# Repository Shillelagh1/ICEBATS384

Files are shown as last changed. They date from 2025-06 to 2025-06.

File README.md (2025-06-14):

**ICE Boards are All The Same.**

> [!CAUTION]
> This project is a heavy work in progress in it's early stages.
> It would be greatly appreciated if you could review and provide feedback on my schematic,
> but it's heavily advised you don't attempt to build this board yet.

> [!IMPORTANT]
> Because of the intended small form factor of this board it may be difficult to manufacture for some.



# Summary:
This board is designed as a small universal FPGA daughterboard that can be added to any project without having to construct a unique layout for each project. It features a 40 pin mezzanine connector to attach to the parent board which offers access to all of the FPGA IO, Clock Hardware Controls, FPGA Configuration controls, and flash programming.

# Hardware:
+ Lattice ICE40LP384-SG32 FPGA.
+ Winbond W25X40C 4MBit Flash.
+ 16MHz Application configurable FPGA Clock.
+ Configuration done and Power OK status LEDs.
+ 2 User program controlled status LEDs.
+ 2mm Clearance daughterboard mezzanine connector.

# Footprint:
+ 30x15mm Overall Size
+ 25x10mm 2xM2 Mounting screw pattern (Diagonal)

# TODO:
- [X] Rough board layout.
- [ ] Peripheral boards (IO Breakout, Programming ribbon board, Automated test board).
- [ ] Final schematic review.
- [ ] First revision prototype.
- [ ] Prototype rework (Or it works first try?)
- [ ] All features test.
- [ ] Project integration.

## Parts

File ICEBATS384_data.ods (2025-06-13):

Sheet: PartsData
Part | Part Desc. | Purpose Desc. | Data Links
ICE40LP384-SG32 | FPGA
W25X40CLUXIG-TR | 4Mbit SPI Config Flash
MCP131T-315E/LB | Reset Controller/ Supervisor | Reset, Power OK
YF4016M00033T1521024: | 16MHz CMOS Oscillator | FPGA Clock
NCP114AMX120TCG | 1.2V LDO | Core Voltage
MCM3400A-TP | 2N-CH MOSFET Array | Status LED Driver
513389873 | 10 Position Mezzanine | Programming | Board-to-Board Connectors Part 513389873 | Molex (https://www.molex.com/en-us/products/part-detail/513389873)
559099872 |  | Mates with ABOVE | Board-to-Board Connectors Part 559099872 | Molex (https://www.molex.com/en-us/products/part-detail/559099872) | NOT PRESENT
5017450401 |  | Board Mating | Board-to-Board Connectors Part 5017450401 | Molex (https://www.molex.com/en-us/products/part-detail/5017450401)
513380474 | 40 Position Mezzanine | Mates with ABOVE | Board-to-Board Connectors Part 513380474 | Molex (https://www.molex.com/en-us/products/part-detail/513380474) | NOT PRESENT

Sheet: J1
Pin No. | Desc. | Pin No. | Desc.
1 | GND | 6 | Flash/FPGA Slave Select
2 | 3V3 | 7 | Config Reset
3 | Flash SDO / FPGA SDI | 8 | Flash Hold
4 | Flash SDI / FPGA SDO | 9 | N.C.
5 | Serial Clock | 10 | GND
In Circuit Flash Program Connection
V2 (Iter. From ICEDEMON board)

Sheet: J2
Part No. | Desc. | Part No. | Desc.
1 | GND | 21 | GND
2 | 3V3 | 22
3 | IO 18 | 23
4 | IO 19 | 24
5 | IO 20 | 25
6 | IO 22 | 26
7 | IO 23 | 27
8 | IO 26 | 28
9 | IO 27 | 29 | IO 15 / SCK
10 |  | 30 | IO 14 / SS
11 | 1V2 | 31 | IO 13 / FPGA SDI / Flash SDO
12 | Flash Hold | 32 | IO 12 / FPGA SDO / Flash SDI
13 | Config Done | 33 | IO 8
14 | Config Reset | 34 | IO 7
15 | Clock Enable | 35 | IO 6
16 | IO 29 | 36 | IO 5
17 | IO 30 | 37 | IO 2
18 | IO 31 | 38 | IO 1
19 | IO 32 | 39 | 3V3
20 | GND | 40 | GND

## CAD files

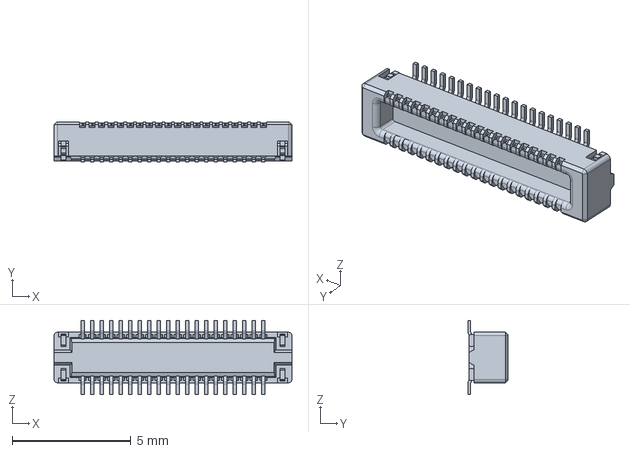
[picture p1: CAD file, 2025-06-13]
parts/daughterConnector/5017450401.stp
10.0 x 1.70 x 3.13 mm

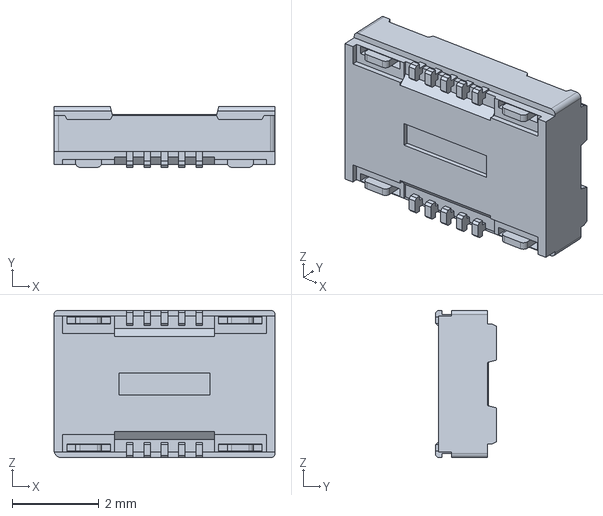
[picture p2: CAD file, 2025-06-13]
parts/prog_con/0513389873.stp
5.10 x 1.40 x 3.40 mm

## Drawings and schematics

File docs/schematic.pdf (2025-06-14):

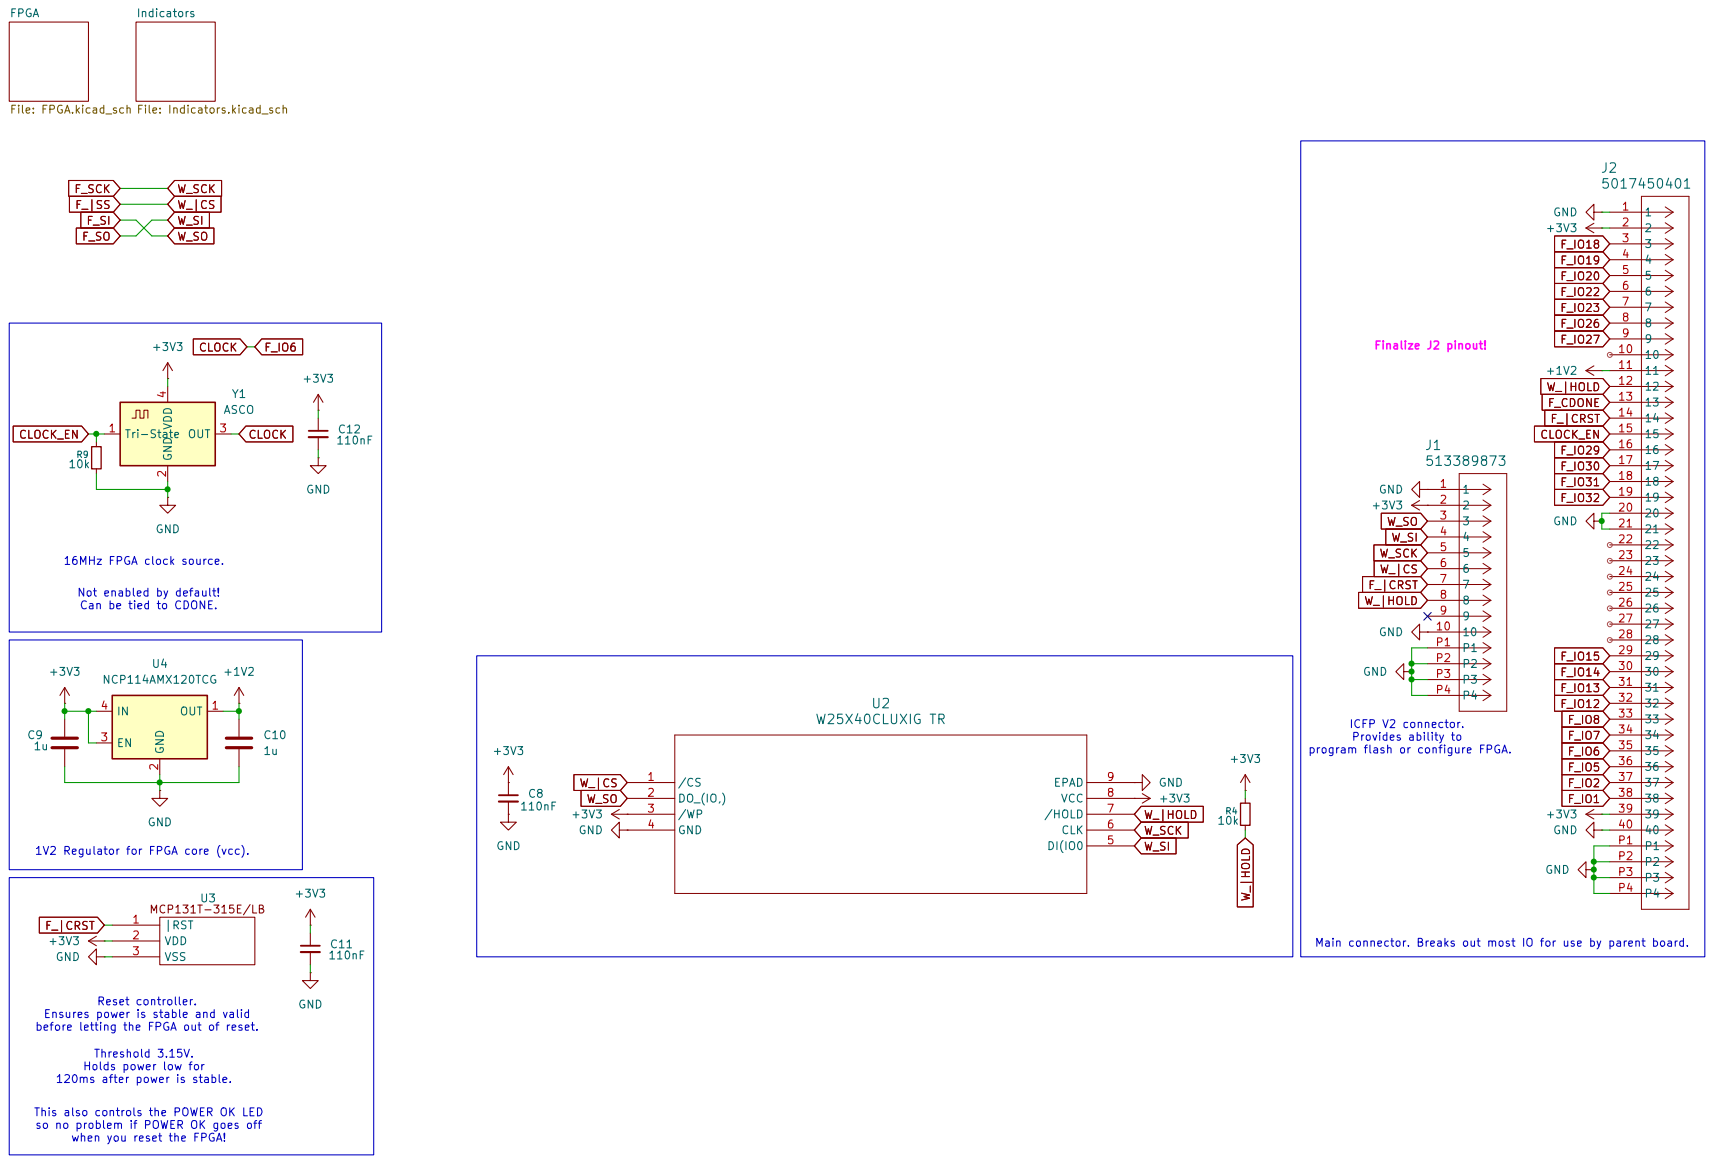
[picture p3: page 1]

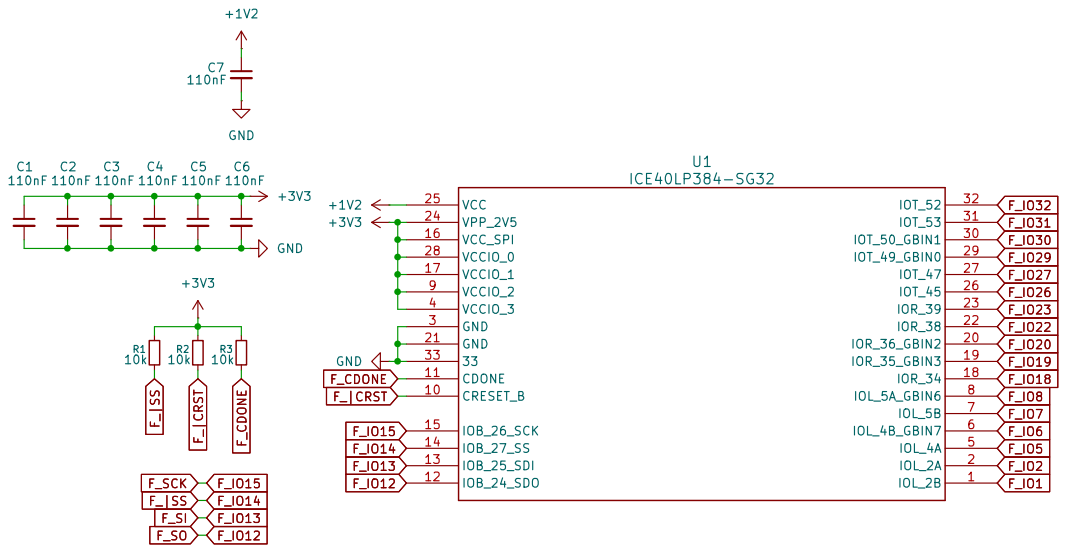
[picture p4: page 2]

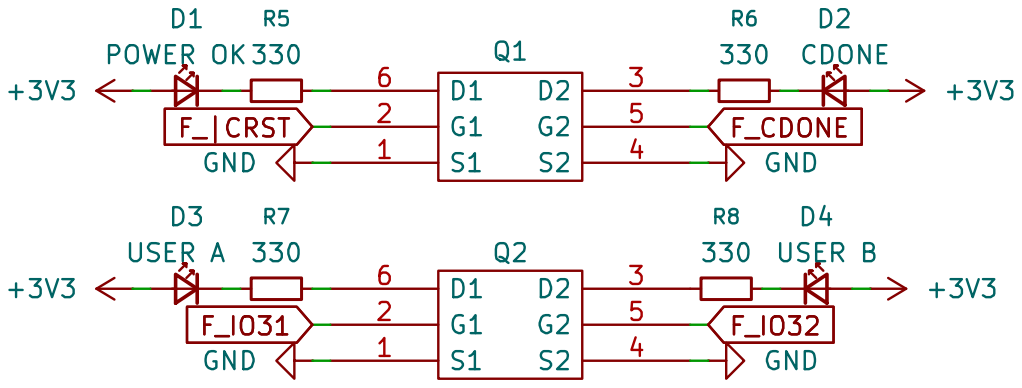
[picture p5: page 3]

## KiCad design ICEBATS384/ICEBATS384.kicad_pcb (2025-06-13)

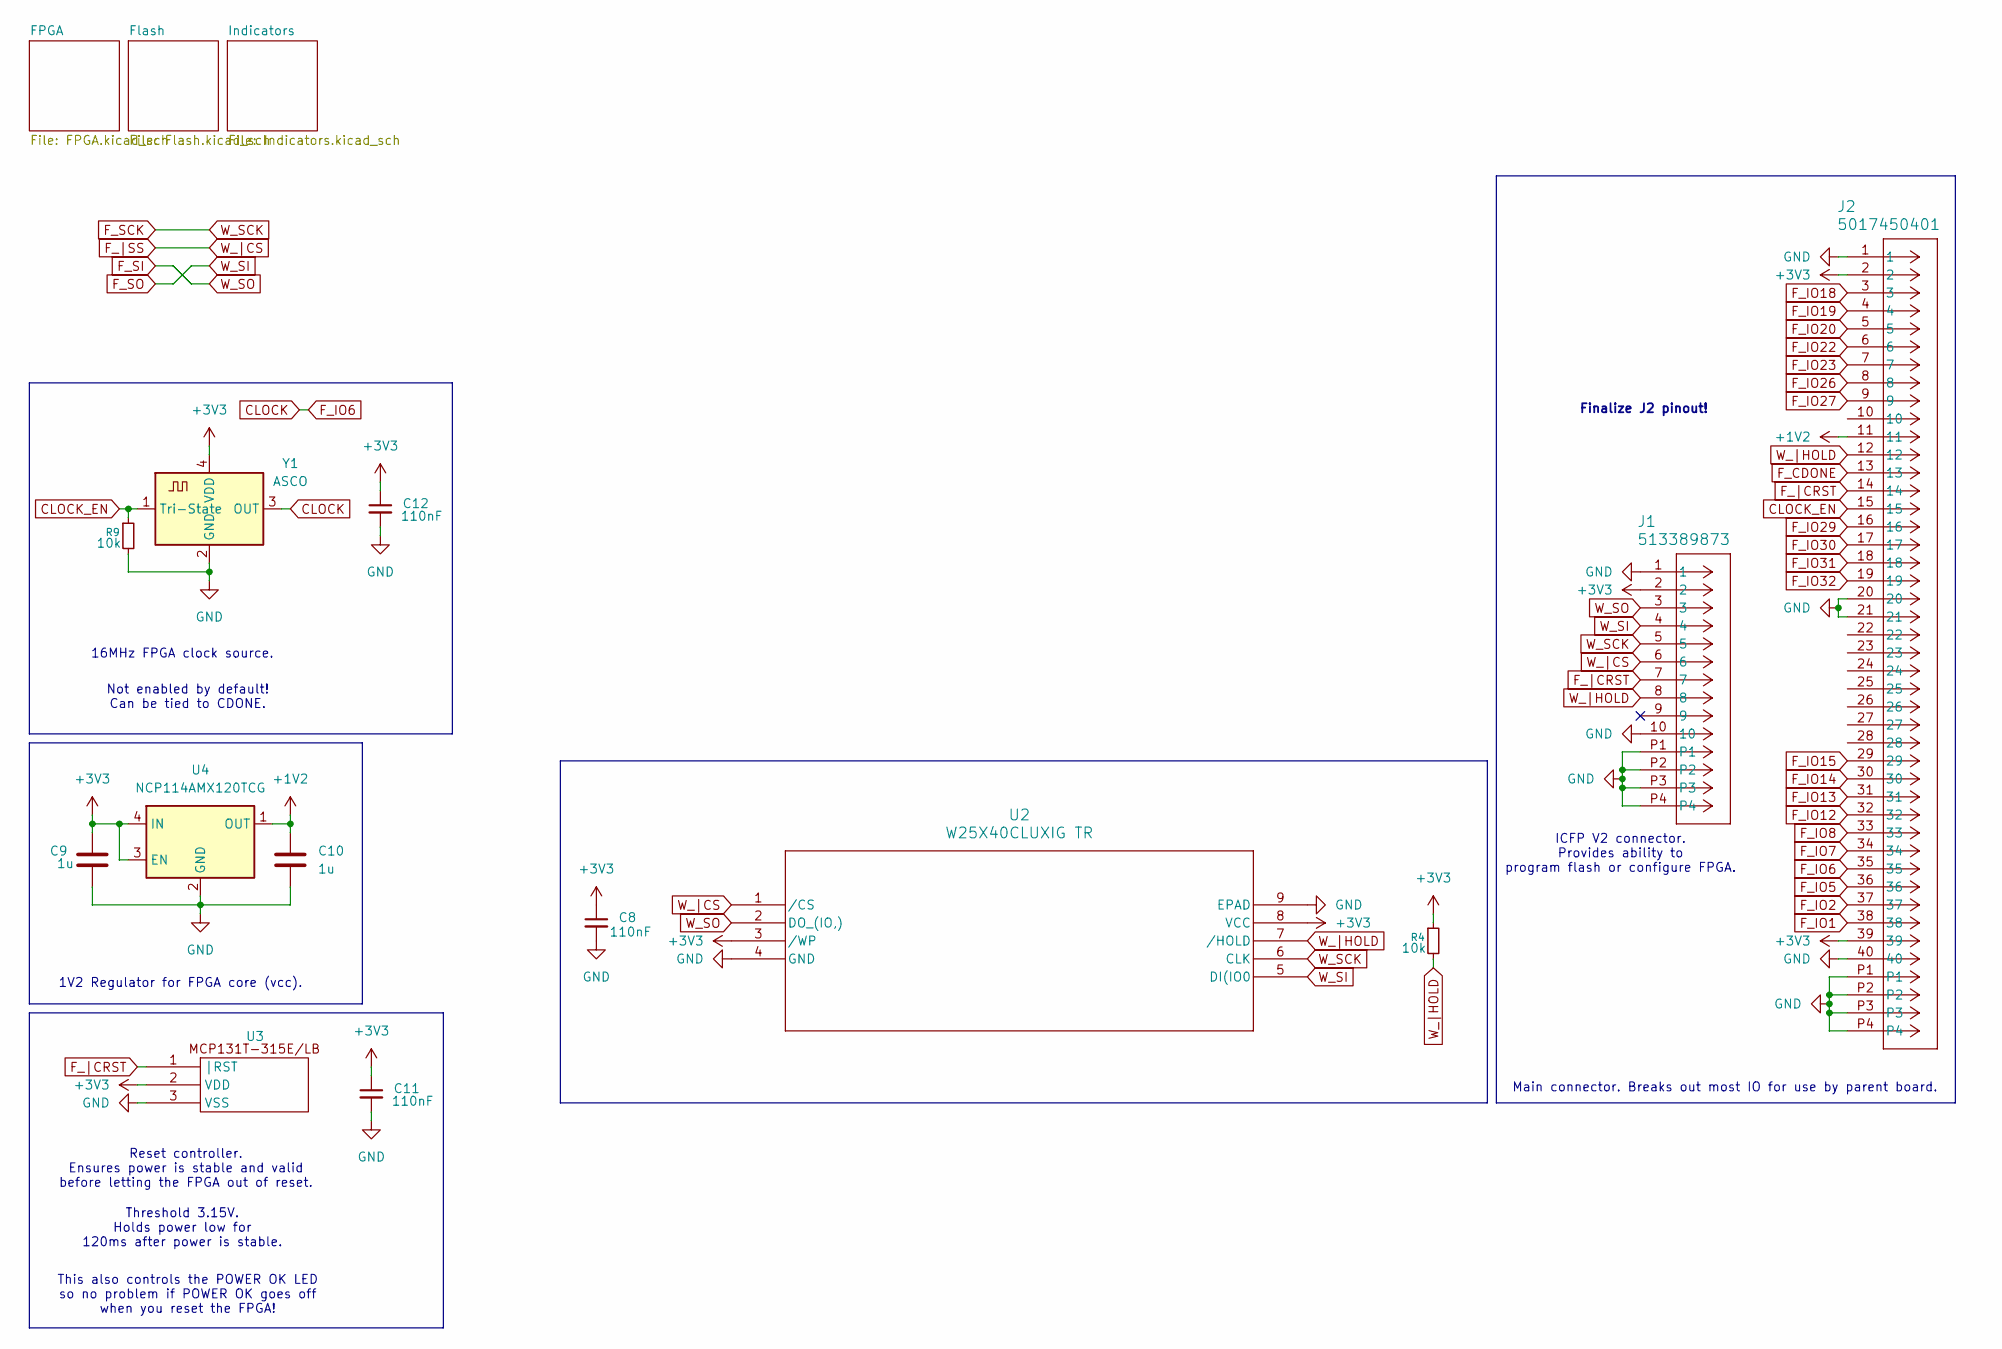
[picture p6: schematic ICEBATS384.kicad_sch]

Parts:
C8, C11, C12: 110nF; C_0402_1005Metric
C9, C10: 1u; C_0603_1608Metric
J1: 513389873; CON_513389873
J2: 5017450401; CON_5017450401
R4, R9: 10k; R_0402_1005Metric
U2: W25X40CLUXIG TR; Winbond_USON-8-1EP_3x2mm_P0.5mm_EP0.2x1.6mm
U3: SOT-323_SC-70
U4: NCP114AMX120TCG; OnSemi_XDFN4-1EP_1.0x1.0mm_EP0.52x0.52mm
Y1: ASCO; Oscillator_SMD_Abracon_ASE-4Pin_3.2x2.5mm

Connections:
+1V2: C10.1, J2.11, U4.1 (OUT); also elsewhere on the board
+3V3: C8.1, C9.1, C11.1, C12.1, J1.2, J2.2, J2.39, R4.1, U2.3 (/WP), U2.8 (VCC), U3.2 (VDD), U4.3 (EN), U4.4 (IN), Y1.4 (VDD); also elsewhere on the board
CLOCK: J2.35, Y1.3 (OUT); also elsewhere on the board
CLOCK_EN: J2.15, R9.1, Y1.1 (Tri-State)
F_CDONE: J2.13; also elsewhere on the board
F_IO1: J2.38; also elsewhere on the board
F_IO2: J2.37; also elsewhere on the board
F_IO5: J2.36; also elsewhere on the board
F_IO7: J2.34; also elsewhere on the board
F_IO8: J2.33; also elsewhere on the board
F_IO12: J1.4, J2.32, U2.5 (DI(IO0); also elsewhere on the board
F_IO13: J1.3, J2.31, U2.2 (DO_(IO,)); also elsewhere on the board
F_IO14: J1.6, J2.30, U2.1 (/CS); also elsewhere on the board
F_IO15: J1.5, J2.29, U2.6 (CLK); also elsewhere on the board
F_IO18: J2.3; also elsewhere on the board
F_IO19: J2.4; also elsewhere on the board
F_IO20: J2.5; also elsewhere on the board
F_IO22: J2.6; also elsewhere on the board
F_IO23: J2.7; also elsewhere on the board
F_IO26: J2.8; also elsewhere on the board
F_IO27: J2.9; also elsewhere on the board
F_IO29: J2.16; also elsewhere on the board
F_IO30: J2.17; also elsewhere on the board
F_IO31: J2.18; also elsewhere on the board
F_IO32: J2.19; also elsewhere on the board
F_|CRST: J1.7, J2.14, U3.1 (|RST); also elsewhere on the board
GND: C8.2, C9.2, C10.2, C11.2, C12.2, J1.1, J1.10, J1.P1, J1.P2, J1.P3, J1.P4, J2.1, J2.20, J2.21, J2.40, J2.P1, J2.P2, J2.P3, J2.P4, R9.2, U2.4 (GND), U2.9 (EPAD), U3.3 (VSS), U4.2 (GND), U4.5 (GND), Y1.2 (GND); also elsewhere on the board
W_|HOLD: J1.8, J2.12, R4.2, U2.7 (/HOLD)

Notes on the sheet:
Main connector. Breaks out most IO for use by parent board.
16MHz FPGA clock source.
Reset controller. Ensures power is stable and valid before letting the FPGA out of reset.
This also controls the POWER OK LED so no problem if POWER OK goes off when you reset the FPGA!
1V2 Regulator for FPGA core (vcc).
Threshold 3.15V. Holds power low for 120ms after power is stable.
ICFP V2 connector. Provides ability to program flash or configure FPGA.
Finalize J2 pinout!
Not enabled by default! Can be tied to CDONE.

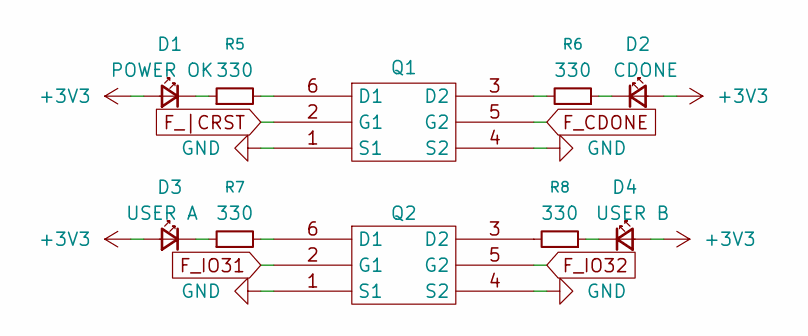
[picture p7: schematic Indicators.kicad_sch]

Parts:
D1: POWER OK; D_0402_1005Metric
D2: CDONE; D_0402_1005Metric
D3: USER A; D_0402_1005Metric
D4: USER B; D_0402_1005Metric
Q1, Q2: DFN-6-1EP_2x2mm_P0.65mm_EP1.01x1.7mm
R5, R6, R7, R8: 330; R_0402_1005Metric

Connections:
+3V3: D1.2 (A), D2.2 (A), D3.2 (A), D4.2 (A); also elsewhere on the board
F_CDONE: Q1.5 (G2); also elsewhere on the board
F_IO31: Q2.2 (G1); also elsewhere on the board
F_IO32: Q2.5 (G2); also elsewhere on the board
F_|CRST: Q1.2 (G1); also elsewhere on the board
GND: Q1.1 (S1), Q1.4 (S2), Q1.7, Q2.1 (S1), Q2.4 (S2), Q2.7; also elsewhere on the board
unnamed: D1.1 (K), R5.1
unnamed: D2.1 (K), R6.1
unnamed: D3.1 (K), R7.1
unnamed: D4.1 (K), R8.1
unnamed: Q1.6 (D1), R5.2
unnamed: Q1.3 (D2), R6.2
unnamed: Q2.6 (D1), R7.2
unnamed: Q2.3 (D2), R8.2

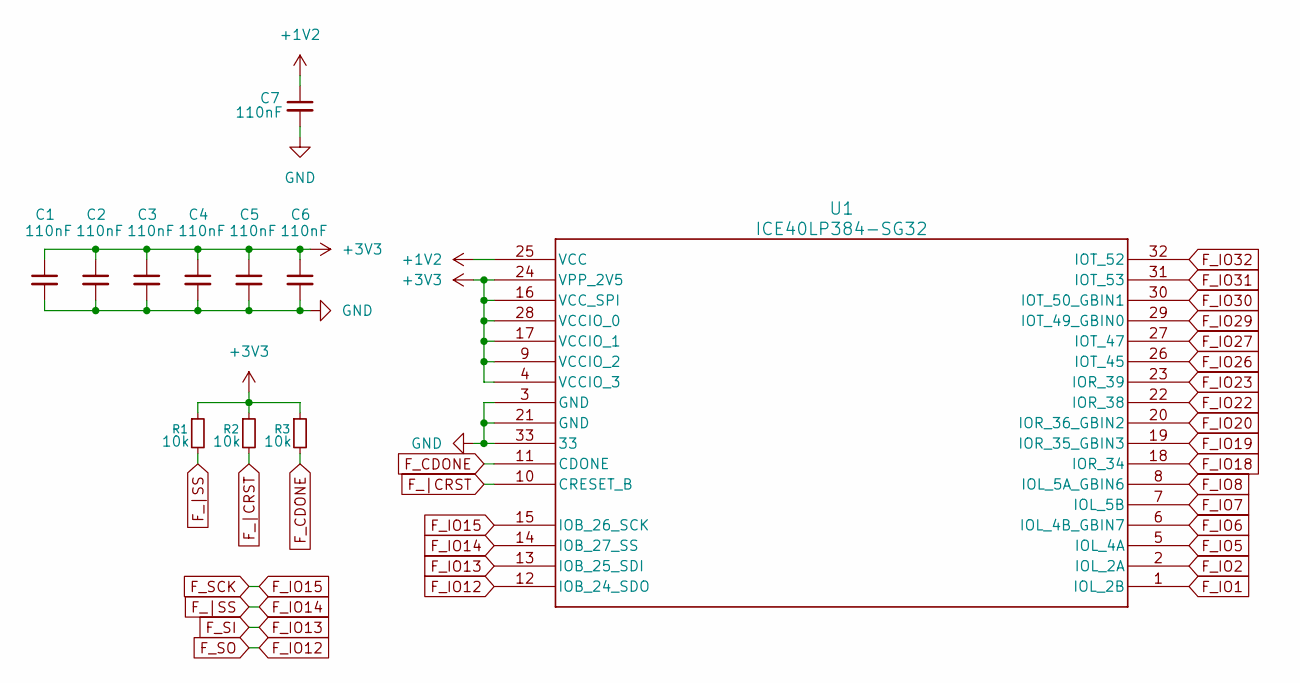
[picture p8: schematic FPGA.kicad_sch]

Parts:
C1, C2, C3, C4, C5, C6, C7: 110nF; C_0402_1005Metric
R1, R2, R3: 10k; R_0402_1005Metric
U1: ICE40LP384-SG32; QFN-32-1EP_5x5mm_P0.5mm_EP3.1x3.1mm

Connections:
+1V2: C7.1, U1.25 (VCC); also elsewhere on the board
+3V3: C1.1, C2.1, C3.1, C4.1, C5.1, C6.1, R1.1, R2.1, R3.1, U1.4 (VCCIO_3), U1.9 (VCCIO_2), U1.16 (VCC_SPI), U1.17 (VCCIO_1), U1.24 (VPP_2V5), U1.28 (VCCIO_0); also elsewhere on the board
CLOCK: U1.6 (IOL_4B_GBIN7); also elsewhere on the board
F_CDONE: R3.2, U1.11 (CDONE); also elsewhere on the board
F_IO1: U1.1 (IOL_2B); also elsewhere on the board
F_IO2: U1.2 (IOL_2A); also elsewhere on the board
F_IO5: U1.5 (IOL_4A); also elsewhere on the board
F_IO7: U1.7 (IOL_5B); also elsewhere on the board
F_IO8: U1.8 (IOL_5A_GBIN6); also elsewhere on the board
F_IO12: U1.12 (IOB_24_SDO); also elsewhere on the board
F_IO13: U1.13 (IOB_25_SDI); also elsewhere on the board
F_IO14: R1.2, U1.14 (IOB_27_SS); also elsewhere on the board
F_IO15: U1.15 (IOB_26_SCK); also elsewhere on the board
F_IO18: U1.18 (IOR_34); also elsewhere on the board
F_IO19: U1.19 (IOR_35_GBIN3); also elsewhere on the board
F_IO20: U1.20 (IOR_36_GBIN2); also elsewhere on the board
F_IO22: U1.22 (IOR_38); also elsewhere on the board
F_IO23: U1.23 (IOR_39); also elsewhere on the board
F_IO26: U1.26 (IOT_45); also elsewhere on the board
F_IO27: U1.27 (IOT_47); also elsewhere on the board
F_IO29: U1.29 (IOT_49_GBIN0); also elsewhere on the board
F_IO30: U1.30 (IOT_50_GBIN1); also elsewhere on the board
F_IO31: U1.31 (IOT_53); also elsewhere on the board
F_IO32: U1.32 (IOT_52); also elsewhere on the board
F_|CRST: R2.2, U1.10 (CRESET_B); also elsewhere on the board
GND: C1.2, C2.2, C3.2, C4.2, C5.2, C6.2, C7.2, U1.3 (GND), U1.21 (GND), U1.33; also elsewhere on the board

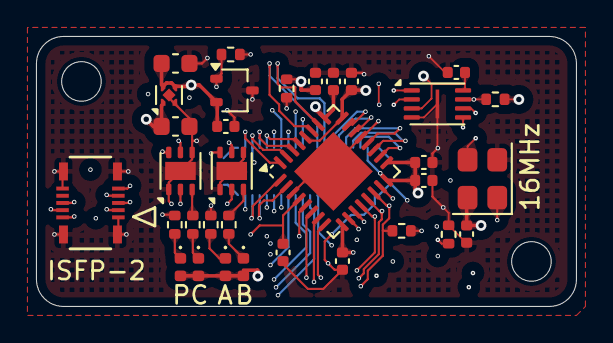
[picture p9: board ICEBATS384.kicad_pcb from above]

Board: 4 copper layers, 30.0 x 15.0 mm, 34 parts (1 on the bottom side), 36 nets.

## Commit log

2025-06-13 Fixes missing schematic connections.
    [Flash.kicad_sch, ICEBATS384.kicad_pcb, ICEBATS384.kicad_sch]
2025-06-13 Fixes board rear silkscreen
    [ICEBATS384.kicad_pcb]
2025-06-13 Sheet documentation
    [FPGA.kicad_sch, Flash.kicad_sch, ICEBATS384.kicad_sch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]
